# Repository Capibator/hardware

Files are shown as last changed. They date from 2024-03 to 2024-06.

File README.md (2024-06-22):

# V1.0 -> First tentative version with following features: 
made with Kicad, 2 layers, lots of vias :D 
- battery monitoring
- battery charge/discharge maintanance LIPO 
- buck boost regulator TPS 
- Source selector that can select between mcu_bat or +12V automatically
- An RTC that can keep time even without battery. helpful for critical memory and notifications. 
- An optional IO expander (PCF) providing 8 extra GPIO. can be left unpopulated. pcb should work fine. 
- MCU used is ESP32 with bluetooth and wifi hopefully both being utillized
- Heater and egg turner both AC, egg turner is the continous type and is the only type currently supported. 
- Main Voltage being used is +12V provided by jack, that will power fans, logic board. incase of power outage heavy stuff will be turned off automatically and it will go into power saving mode. 
- Outputs (All 12V)
    - Fan Exhaust 
    - Fan Continous 
    - Mist Maker 
    - LED lights 
    - Buzzer
    - Water Pump 
- Sensors/Inputs
    - Water level sensor
    - Display (I2C)
    - Rotary encoder for menu (left, right and click)
    - Temperature sensor (1 wire or digital)
    - Temperature sensor #2 (1 wire or digital)
- Indicators
    - Fault led, will light up if something is wrong according to code
    - Busy led, will turn on when turning eggs or saving to memory 
    - Con led, shows connectivity of wifi, if connected will light up
    - IO led, custom function or initial testing. 
    - Main power indicator led that will light up when 12V is connected through barrel jack. 

This is how it looks as of right now. 
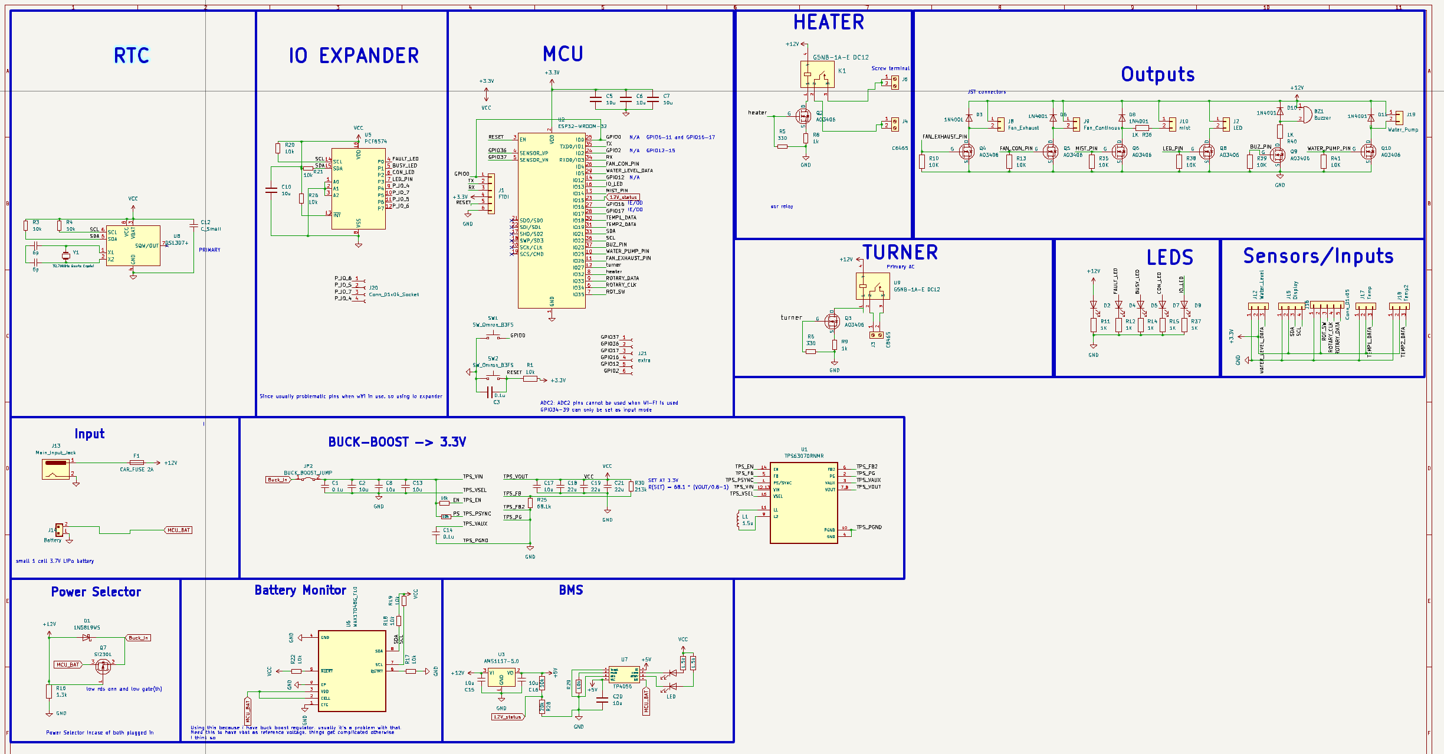
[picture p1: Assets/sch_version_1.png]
Version 1 schematic

PCB 
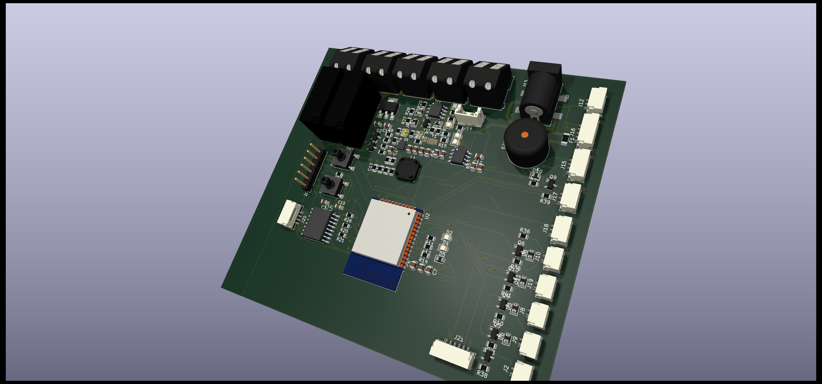
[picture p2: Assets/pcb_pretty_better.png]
Version 1 pcb


# Version 2 
Better placement, hopefully this is better. 
AC in one end and sensitive logic on the other. 
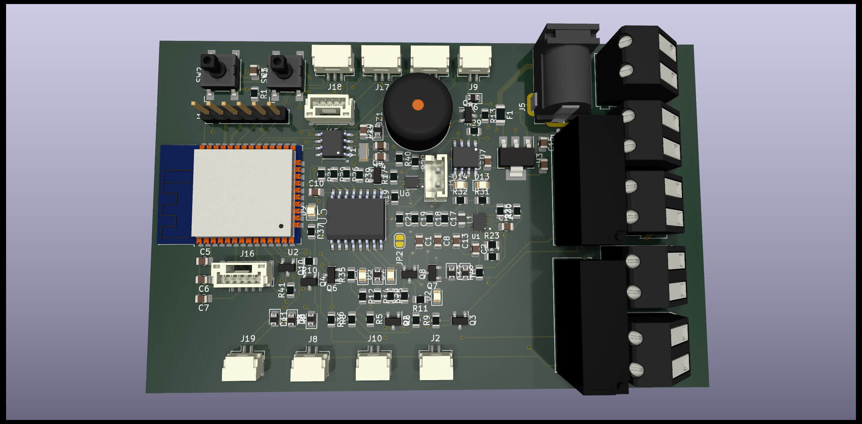
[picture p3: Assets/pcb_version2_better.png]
Version 2 pcb


size 101.5mm x 61.4mm

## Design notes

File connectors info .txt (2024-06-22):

connector consideration
group 1 small signal only and mA
temp1 3
temp2 3
water level 3

group 2 power 200
water pump 2
led 2
mist 2
fan continous 2
fan exhaust 2

group 3 signal only.
pcf extra 4 signal 
gpio 6 extra signal 
3.3V and gnd 

group 4
jst xh maybe? just signal
display 4 
rotary encoder 5

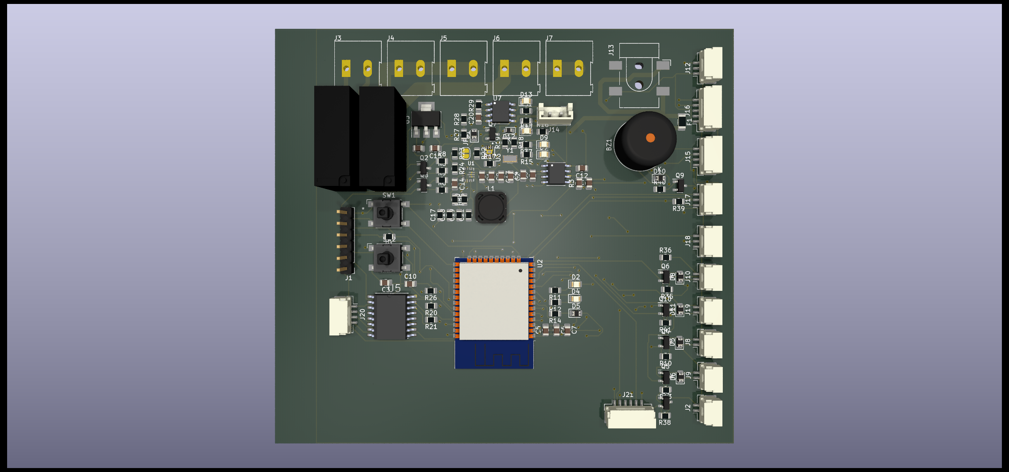
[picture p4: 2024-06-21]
Assets/pcb_pretty.png

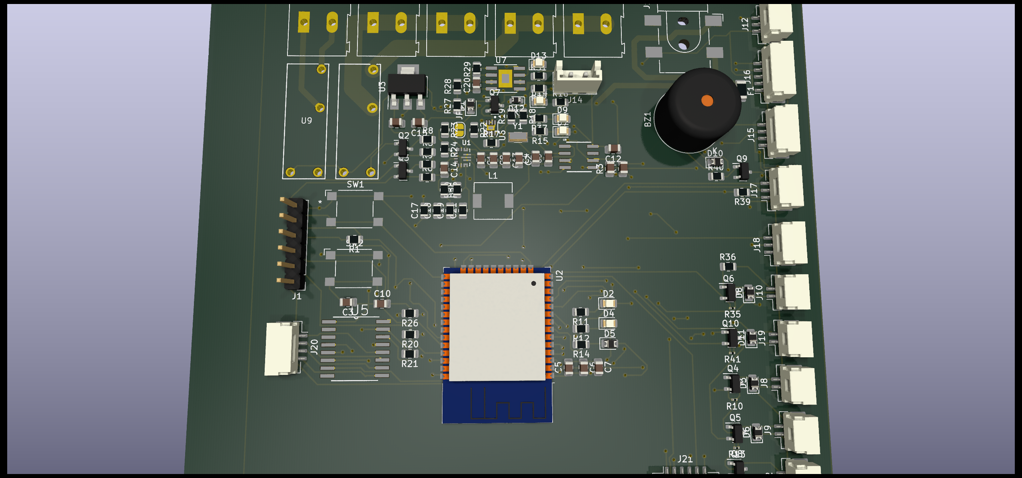
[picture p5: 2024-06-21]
Capibator_PCB_3DVIEW.png

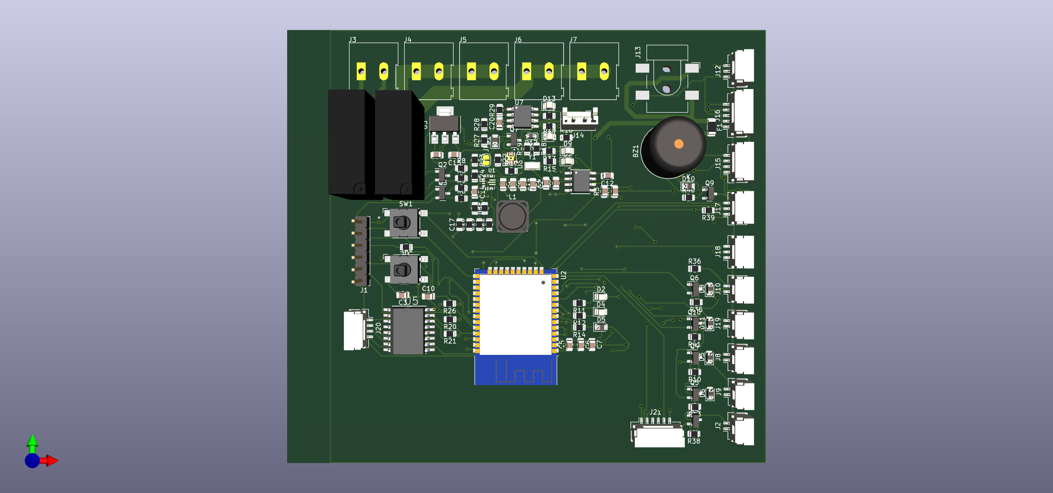
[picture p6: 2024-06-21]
Assets/pcb_simple.png

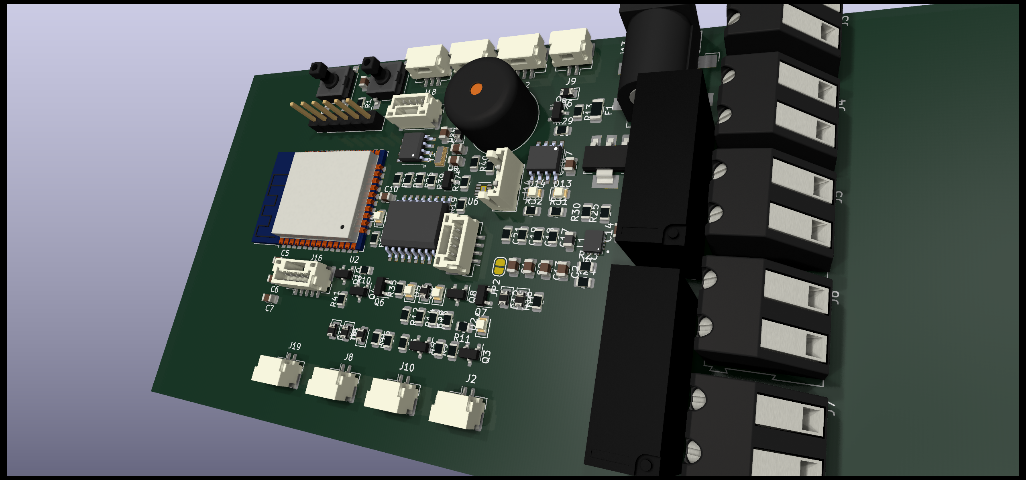
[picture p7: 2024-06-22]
Assets/version_2.png

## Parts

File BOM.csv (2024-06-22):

Reference | Value | Datasheet | Footprint | Qty | DNP
BZ1 | Buzzer | ~ | Buzzer_Beeper:Buzzer_12x9.5RM7.6 | 1
C1,C3,C14 | 0.1u | ~ | Capacitor_SMD:C_0805_2012Metric | 3
C2,C5,C6,C7,C8,C10,C13,C15,C16,C17,C20 | 10u | ~ | -- mixed values -- | 11
C4,C9 | 6p | ~ | Capacitor_SMD:C_0805_2012Metric | 2
C12 | C_Small | ~ | Capacitor_SMD:C_0805_2012Metric | 1
C18,C19,C21 | 22u | ~ | Resistor_SMD:R_0805_2012Metric | 3
D1 | 1N5819WS | https://datasheet.lcsc.com/lcsc/2204281430_Guangdong-Hottech-1N5819WS_C191023.pdf | Diode_SMD:D_0805_2012Metric | 1
D2 | LED_PWR | ~ | LED_SMD:LED_0805_2012Metric | 1
D3,D6,D8,D10,D11 | 1N4001 | http://www.vishay.com/docs/88503/1n4001.pdf | Diode_SMD:D_0805_2012Metric | 5
D4 | FAULT_LED | ~ | LED_SMD:LED_0805_2012Metric | 1
D5 | BUSY_LED | ~ | Diode_SMD:D_0805_2012Metric | 1
D7 | CONNECTIVITY_LED | ~ | LED_SMD:LED_0805_2012Metric | 1
D9,D13,D14,J2 | LED | ~ | -- mixed values -- | 4
F1 | CAR_FUSE 2A | ~ | Fuse:Fuse_1206_3216Metric | 1
J1 | FTDI | ~ | Connector_PinHeader_2.54mm:PinHeader_1x06_P2.54mm_Vertical | 1
J3,J4,J6 | C8465 | ~ | TerminalBlock:TerminalBlock_Altech_AK300-2_P5.00mm | 3
J5 | PJ-002AH |  | PJ-002AH:CUI_PJ-002AH | 1
J8 | Fan_Exhaust | ~ | Connector_JST:JST_GH_SM02B-GHS-TB_1x02-1MP_P1.25mm_Horizontal | 1
J9 | Fan_Continous | ~ | Connector_JST:JST_GH_SM02B-GHS-TB_1x02-1MP_P1.25mm_Horizontal | 1
J10 | mist | ~ | Connector_JST:JST_GH_SM02B-GHS-TB_1x02-1MP_P1.25mm_Horizontal | 1
J12 | Water_Level | ~ | Connector_JST:JST_GH_SM03B-GHS-TB_1x03-1MP_P1.25mm_Horizontal | 1
J14 | Battery |  | Connector_JST:JST_EH_B2B-EH-A_1x02_P2.50mm_Vertical | 1
J15 | Display | ~ | Connector_JST:JST_GH_BM04B-GHS-TBT_1x04-1MP_P1.25mm_Vertical | 1
J16 | Rotary encoder | ~ | Connector_JST:JST_GH_BM05B-GHS-TBT_1x05-1MP_P1.25mm_Vertical | 1
J17 | Temp | ~ | Connector_JST:JST_GH_SM03B-GHS-TB_1x03-1MP_P1.25mm_Horizontal | 1
J18 | Temp2 | ~ | Connector_JST:JST_GH_SM03B-GHS-TB_1x03-1MP_P1.25mm_Horizontal | 1
J19 | Water_Pump | ~ | Connector_JST:JST_GH_SM02B-GHS-TB_1x02-1MP_P1.25mm_Horizontal | 1
JP2 | BUCK_BOOST_JUMP | ~ | Jumper:SolderJumper-2_P1.3mm_Bridged_RoundedPad1.0x1.5mm | 1
K1,U9 | G5NB-1A-E DC12 | -- mixed values -- | G5NB-1A-E_DC12:RELAY_G5NB-1A_DC5_OMR | 2
L1 | 1.5u | ~ | Inductor_SMD:L_0805_2012Metric | 1
Q2,Q3,Q4,Q5,Q6,Q8,Q9,Q10 | AO3406 | https://ngspice.sourceforge.io/docs/ngspice-manual.pdf | Package_TO_SOT_SMD:SOT-23 | 8
Q7 | SI2301 | http://www.vishay.com/docs/66709/si2319cd.pdf | Package_TO_SOT_SMD:SOT-23 | 1
R1,R17,R20,R21,R22,R23,R24,R26,R29 | 10k | ~ | Resistor_SMD:R_0805_2012Metric | 9
R5,R6 | 330 | ~ | Resistor_SMD:R_0805_2012Metric | 2
R8,R9 | 1k | ~ | Resistor_SMD:R_0805_2012Metric | 2
R10,R13,R35,R38,R39,R41 | 10K | ~ | Resistor_SMD:R_0805_2012Metric | 6
R11,R12,R14,R15,R36,R37,R40 | 1K | ~ | Resistor_SMD:R_0805_2012Metric | 7
R16 | 1.3k | ~ | Resistor_SMD:R_0805_2012Metric | 1
R25 | 68.1k | ~ | Resistor_SMD:R_0805_2012Metric | 1
R30 | 213k | ~ | Resistor_SMD:R_0805_2012Metric | 1
R31,R32 | 1.5k | ~ | Resistor_SMD:R_0805_2012Metric | 2
SW1,SW2 | SW_Omron_B3FS | https://omronfs.omron.com/en_US/ecb/products/pdf/en-b3fs.pdf | Button_Switch_SMD:SW_SPST_Omron_B3FS-100xP | 2
U1 | TPS63070RNMR |  | TPS63070RNMR:VREG_TPS63070RNMR | 1
U2 | ESP32-WROOM-32 | https://www.espressif.com/sites/default/files/documentation/esp32-wroom-32_datasheet_en.pdf | RF_Module:ESP32-WROOM-32 | 1
U3 | AMS1117-5.0 | http://www.advanced-monolithic.com/pdf/ds1117.pdf | Package_TO_SOT_SMD:SOT-223-3_TabPin2 | 1
U5 | PCF8574 | http://www.nxp.com/docs/en/data-sheet/PCF8574_PCF8574A.pdf | PCF8574T_3_518:SOIC127P1032X265-16N | 1
U6 | MAX17048G_T10 |  | MAX17048G_T10:SON50P200X200X80-9N | 1
U7 | TP4056 |  | TP4056:SOP127P600X175-9N | 1
U8 | DS1307+ | https://datasheets.maximintegrated.com/en/ds/DS1307.pdf | DS1307ZTR:21-0041B_8 | 1
Y1 | 32.768kHz Quartz Crystal | ~ | Crystal:Crystal_SMD_3215-2Pin_3.2x1.5mm | 1

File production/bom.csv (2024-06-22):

Designator | Footprint | Quantity | Value | LCSC Part #
BZ1 | Buzzer_12x9.5RM7.6 | 1 | Buzzer
C1, C14, C3 | 0805 | 3 | 0.1u
C10, C12, C13, C15, C16, C17, C2, C20, C5, C6, C7, C8 | 0805 | 12 | 10u
C18, C19, C21 | 0805 | 3 | 22u
C4, C9 | 0805 | 2 | 6p
D1 | D_SOD-323F | 1 | 1N5819WS
D10, D11, D3, D6, D8 | D_SOD-123F | 5 | 1N4001
D13, D14, D9 | 0805 | 3 | LED
D2 | 0805 | 1 | LED_PWR
D4 | 0805 | 1 | FAULT_LED
D5 | 0805 | 1 | BUSY_LED
D7 | 0805 | 1 | CONNECTIVITY_LED
J1 | PinHeader_1x06_P2.54mm_Vertical | 1 | FTDI
J10 | JST_GH_SM02B-GHS-TB_1x02-1MP_P1.25mm_Horizontal | 1 | mist
J12 | JST_GH_SM03B-GHS-TB_1x03-1MP_P1.25mm_Horizontal | 1 | Water_Level
J14 | JST_EH_B2B-EH-A_1x02_P2.50mm_Vertical | 1 | Battery
J15 | JST_GH_BM04B-GHS-TBT_1x04-1MP_P1.25mm_Vertical | 1 | Display
J16 | JST_GH_BM05B-GHS-TBT_1x05-1MP_P1.25mm_Vertical | 1 | Rotary encoder
J17 | JST_GH_SM03B-GHS-TB_1x03-1MP_P1.25mm_Horizontal | 1 | Temp
J18 | JST_GH_SM03B-GHS-TB_1x03-1MP_P1.25mm_Horizontal | 1 | Temp2
J19 | JST_GH_SM02B-GHS-TB_1x02-1MP_P1.25mm_Horizontal | 1 | Water_Pump
J2 | JST_GH_SM02B-GHS-TB_1x02-1MP_P1.25mm_Horizontal | 1 | LED
J3, J4, J6 | TerminalBlock_Altech_AK300-2_P5.00mm | 3 | C8465
J5_2 | CUI_PJ-002AH | 1 | PJ-002AH
J5, J7 | TerminalBlock_Altech_AK300-2_P5.00mm | 2 | Screw_Terminal_01x02
J8 | JST_GH_SM02B-GHS-TB_1x02-1MP_P1.25mm_Horizontal | 1 | Fan_Exhaust
J9 | JST_GH_SM02B-GHS-TB_1x02-1MP_P1.25mm_Horizontal | 1 | Fan_Continous
JP2 | SolderJumper-2_P1.3mm_Bridged_RoundedPad1.0x1.5mm | 1 | BUCK_BOOST_JUMP
K1, U9 | RELAY_G5NB-1A_DC5_OMR | 2 | G5NB-1A-E DC12
L1 | L_Murata_LQH2MCNxxxx02_2.0x1.6mm | 1 | 1.5u
Q10, Q2, Q3, Q4, Q5, Q6, Q8, Q9 | SOT-23 | 8 | AO3406
Q7 | SOT-23 | 1 | SI2301
R1, R10, R13, R17, R19, R20, R21, R22, R23, R24, R26, R29, R35, R38, R39, R41 | 0805 | 16 | 10k
R11, R12, R14, R15, R31, R32, R37 | 0805 | 7 | 100
R16 | 0805 | 1 | 1.3k
R2 | 0805 | 1 | 3k
R25 | 0805 | 1 | 68.1k
R30 | 0805 | 1 | 210k
R36 | D_SOD-123F | 1 | 1K
R40, R8, R9 | 0805 | 3 | 1K
R5, R6 | 0805 | 2 | 330
SW1, SW2 | SW_SPST_Omron_B3FS-100xP | 2 | SW_Omron_B3FS
U1 | VREG_TPS63070RNMR | 1 | TPS63070RNMR
U2 | ESP32-WROOM-32 | 1 | ESP32-WROOM-32
U3 | SOT-223-3_TabPin2 | 1 | AMS1117-5.0
U5 | SOIC127P1032X265-16N | 1 | PCF8574
U6 | SON50P200X200X80-9N | 1 | MAX17048G_T10
U7 | SOP127P600X175-9N | 1 | TP4056
U8 | 21-0041B_8 | 1 | DS1307+
Y1 | Crystal_SMD_2012-2Pin_2.0x1.2mm_HandSoldering | 1 | 32.768kHz Quartz Crystal

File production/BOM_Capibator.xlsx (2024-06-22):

Designator | Footprint | Quantity | Value | LCSC Part #
BZ1 | Buzzer_12x9.5RM7.6 | 1 | Buzzer | C7496513 (https://www.lcsc.com/product-detail/Buzzers_KINGSTATE-KXG1212C_C7496513.html)
C1, C14, C3 | 805 | 3 | 0.1u | C49678 (https://www.lcsc.com/product-detail/Multilayer-Ceramic-Capacitors-MLCC-SMD-SMT_YAGEO-CC0805KRX7R9BB104_C49678.html)
C10, C12, C13, C15, C16, C17, C2, C20, C5, C6, C7, C8 | 805 | 12 | 10u | C40894 (https://www.lcsc.com/product-detail/Multilayer-Ceramic-Capacitors-MLCC-SMD-SMT_FH-Guangdong-Fenghua-Advanced-Tech-0805X106K250NT_C40894.html)
C18, C19, C21 | 805 | 3 | 22u | C129303 (https://www.lcsc.com/product-detail/Multilayer-Ceramic-Capacitors-MLCC-SMD-SMT_FH-Guangdong-Fenghua-Advanced-Tech-0805X226M250NT_C129303.html)
C4, C9 | 805 | 2 | 6p | C67560 (https://www.lcsc.com/product-detail/Multilayer-Ceramic-Capacitors-MLCC-SMD-SMT_FH-Guangdong-Fenghua-Advanced-Tech-0805CG6R0C500NT_C67560.html)
D1 | D_SOD-323F | 1 | 1N5819WS | C727116 (https://www.lcsc.com/product-detail/Schottky-Barrier-Diodes-SBD_TWGMC-1N5819WS_C727116.html)
D10, D11, D3, D6, D8 | D_SOD-123F | 5 | 1N4001 | C2892326 (https://www.lcsc.com/product-detail/Diodes-General-Purpose_YONGYUTAI-1N4001_C2892326.html)
D13, D9, D5, D2, D14, D4, D7 | 805 | 3 | LED | C5349940 (https://www.lcsc.com/product-detail/Light-Emitting-Diodes-LED_XINGLIGHT-XL-TD2012UBC_C5349940.html)
J1 | PinHeader_1x06_P2.54mm_Vertical | 1 | FTDI | C19190481 (https://www.lcsc.com/product-detail/Pin-Headers_Yxcon-P125-1106A0BS116A1_C19190481.html)
J10 | JST_GH_SM02B-GHS-TB_1x02-1MP_P1.25mm_Horizontal | 1 | mist | C160402 (https://www.lcsc.com/product-detail/Wire-To-Board-Connector_JST-SM02B-SRSS-TB-LF-SN_C160402.html)
J12 | JST_GH_SM03B-GHS-TB_1x03-1MP_P1.25mm_Horizontal | 1 | Water_Level | C514175 (https://www.lcsc.com/product-detail/Wire-To-Board-Connector_JST-SM03B-GHS-TB-LF-SN_C514175.html)
J14 | JST_EH_B2B-EH-A_1x02_P2.50mm_Vertical | 1 | Battery | C160262 (https://www.lcsc.com/product-detail/Wire-To-Board-Connector_JST-B2B-EH-A-LF-SN_C160262.html)
J15 | JST_GH_BM04B-GHS-TBT_1x04-1MP_P1.25mm_Vertical | 1 | Display | C161692 (https://www.lcsc.com/product-detail/Wire-To-Board-Connector_JST-BM04B-GHS-TBT-LF-SN_C161692.html)
J16 | JST_GH_BM05B-GHS-TBT_1x05-1MP_P1.25mm_Vertical | 1 | Rotary encoder | C189891 (https://www.lcsc.com/product-detail/Wire-To-Board-Connector_JST-BM05B-GHS-TBT-LF-SN-N_C189891.html)
J17 | JST_GH_SM03B-GHS-TB_1x03-1MP_P1.25mm_Horizontal | 1 | Temp | C514175 (https://www.lcsc.com/product-detail/Wire-To-Board-Connector_JST-SM03B-GHS-TB-LF-SN_C514175.html)
J18 | JST_GH_SM03B-GHS-TB_1x03-1MP_P1.25mm_Horizontal | 1 | Temp2 | C514175 (https://www.lcsc.com/product-detail/Wire-To-Board-Connector_JST-SM03B-GHS-TB-LF-SN_C514175.html)
J19 | JST_GH_SM02B-GHS-TB_1x02-1MP_P1.25mm_Horizontal | 1 | Water_Pump | C189893 (https://www.lcsc.com/product-detail/Wire-To-Board-Connector_JST-SM02B-GHS-TB-LF-SN_C189893.html)
J2 | JST_GH_SM02B-GHS-TB_1x02-1MP_P1.25mm_Horizontal | 1 | LED | C189893 (https://www.lcsc.com/product-detail/Wire-To-Board-Connector_JST-SM02B-GHS-TB-LF-SN_C189893.html)
J3, J4, J6, J5, J7 | TerminalBlock_Altech_AK300-2_P5.00mm | 3 | terminal_con | C8465 (https://www.lcsc.com/product-detail/Screw-terminal_Ningbo-Kangnex-Elec-WJ500V-5-08-2P_C8465.html)
J20 | CUI_PJ-002AH | 1 | PJ-002AH | C319099 (https://www.lcsc.com/product-detail/span-style-background-color-ff0-DC-span-Power-Connector_XKB-Connection-DC-005-2-5A-2-0_C319099.html)
J8 | JST_GH_SM02B-GHS-TB_1x02-1MP_P1.25mm_Horizontal | 1 | Fan_Exhaust | C189893 (https://www.lcsc.com/product-detail/Wire-To-Board-Connector_JST-SM02B-GHS-TB-LF-SN_C189893.html)
J9 | JST_GH_SM02B-GHS-TB_1x02-1MP_P1.25mm_Horizontal | 1 | Fan_Continous | C189893 (https://www.lcsc.com/product-detail/Wire-To-Board-Connector_JST-SM02B-GHS-TB-LF-SN_C189893.html)
K1, U9 | RELAY_G5NB-1A_DC5_OMR | 2 | G5NB-1A-E DC12 | C225714 (https://www.lcsc.com/product-detail/Power-Relays_Omron-Electronics-G5NB-1A-E-DC12_C225714.html)
L1 | L_Murata_LQH2MCNxxxx02_2.0x1.6mm | 1 | 1.5u | C326262 (https://www.lcsc.com/product-detail/Inductors-SMD_3-span-style-background-color-ff0-L-span-COILS-SNR2010K-1R5M_C326262.html)
Q10, Q2, Q3, Q4, Q5, Q6, Q8, Q9 | SOT-23 | 8 | AO3406 | C2909910 (https://www.lcsc.com/product-detail/MOSFETs_KUU-AO3406_C2909910.html)
Q7 | SOT-23 | 1 | SI2301 | C5261052 (https://www.lcsc.com/product-detail/MOSFETs_HXY-MOSFET-SI2301-ZE_C5261052.html)
R1, R10, R13, R17, R19, R20, R21, R22, R23, R24, R26, R29, R35, R38, R39, R41 | 805 | 16 | 10k | C17414 (https://www.lcsc.com/product-detail/Chip-Resistor-Surface-Mount_UNI-ROYAL-Uniroyal-Elec-0805W8F1002T5E_C17414.html)
R11, R12, R14, R15, R31, R32, R37 | 805 | 9 | 100 | C17408 (https://www.lcsc.com/product-detail/Chip-Resistor-Surface-Mount_UNI-ROYAL-Uniroyal-Elec-0805W8F1000T5E_C17408.html)
R16 | 805 | 1 | 1.3k | C2933303 (https://www.lcsc.com/product-detail/Chip-Resistor-Surface-Mount_FOJAN-FRC0805F1301TS_C2933303.html)
R2 | 805 | 1 | 3k | C109322 (https://www.lcsc.com/product-detail/DC-DC-Converters_Texas-Instruments-TPS63070RNMR_C109322.html)
R25 | 805 | 1 | 68.1k | C17795 (https://www.lcsc.com/product-detail/Chip-Resistor-Surface-Mount_UNI-ROYAL-Uniroyal-Elec-0805W8F6812T5E_C17795.html)
R30 | 805 | 1 | 210k | C17547 (https://www.lcsc.com/product-detail/Chip-Resistor-Surface-Mount_UNI-ROYAL-Uniroyal-Elec-0805W8F2103T5E_C17547.html)
R36, R40, R8, R9 | 805 | 4 | 1K | C17513 (https://www.lcsc.com/product-detail/Chip-Resistor-Surface-Mount_UNI-ROYAL-Uniroyal-Elec-0805W8F1001T5E_C17513.html)
SW1, SW2 | SW_SPST_Omron_B3FS-100xP | 2 | SW_Omron_B3FS | C87038 (https://www.lcsc.com/product-detail/Tactile-Switches_Omron-Electronics-B3FS-1002P_C87038.html)
U1 | VREG_TPS63070RNMR | 1 | TPS63070RNMR | C109322 (https://www.lcsc.com/product-detail/DC-DC-Converters_Texas-Instruments-TPS63070RNMR_C109322.html)
U2 | ESP32-WROOM-32 | 1 | ESP32-WROOM-32 | C701342 (https://www.lcsc.com/product-detail/WiFi-Modules_Espressif-Systems-ESP32-WROOM-32E-N8_C701342.html)
U3 | SOT-223-3_TabPin2 | 1 | AMS1117-5.0 | C18212701 (https://www.lcsc.com/product-detail/Linear-Voltage-Regulators-LDO_TECH-PUBLIC-AMS1117-5-0_C18212701.html)
U5 | SOIC127P1032X265-16N | 1 | PCF8574 | C2987288 (https://www.lcsc.com/product-detail/I-O-Expanders_HGSEMI-PCF8574T-TR_C2987288.html)
U6 | SON50P200X200X80-9N | 1 | MAX17048G_T10 | C2682616 (https://www.lcsc.com/product-detail/Battery-Management-ICs_Analog-Devices-Inc-Maxim-Integrated-MAX17048G-T10_C2682616.html)
U7 | SOP127P600X175-9N | 1 | TP4056 | C16581 (https://www.lcsc.com/product-detail/Battery-Management-ICs_TOPPOWER-Nanjing-Extension-Microelectronics-TP4056-42-ESOP8_C16581.html)
U8 | 21-0041B_8 | 1 | DS1307+ | C5145427 (https://www.lcsc.com/product-detail/Real-Time-Clocks-RTC_HANSCHIP-semiconductor-DS1307CDRG_C5145427.html)
Y1 | Crystal_SMD_2012-2Pin_2.0x1.2mm_HandSoldering | 1 | 32.768kHz Quartz Crystal | C620155 (https://www.lcsc.com/product-detail/Crystals_YXC-Crystal-Oscillators-X321532768KGD2SI_C620155.html)

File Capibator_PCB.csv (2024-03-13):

# | Reference | Qty | Value | Footprint | DNP
1 | BZ1 | 1 | Buzzer | Buzzer_Beeper:Buzzer_12x9.5RM7.6
2 | C1, C3, C14 | 3 | 0.1u | Capacitor_SMD:C_0402_1005Metric
3 | C2, C5, C6, C7, C8, C13, C15, C17, C20 | 9 | 10u | Capacitor_SMD:C_0402_1005Metric
4 | C4, C9 | 2 | 6p | Capacitor_SMD:C_0402_1005Metric
5 | C12 | 1 | C_Small | Capacitor_SMD:C_0402_1005Metric
6 | C16 | 1 | 10u | Capacitor_SMD:C_0805_2012Metric
7 | C18, C19, C21 | 3 | 22u | Capacitor_SMD:C_0402_1005Metric
8 | D2 | 1 | LED_PWR | LED_SMD:LED_0805_2012Metric
9 | D3, D6, D8, D10, D11 | 5 | 1N4001 | Diode_SMD:D_0805_2012Metric
10 | D4 | 1 | FAULT_LED | LED_SMD:LED_0805_2012Metric
11 | D5 | 1 | BUSY_LED | Diode_SMD:D_0805_2012Metric
12 | D7 | 1 | CONNECTIVITY_LED | LED_SMD:LED_0805_2012Metric
13 | D9, D13, D14 | 3 | LED | LED_SMD:LED_0805_2012Metric
14 | D12 | 1 | 1N5819 | Diode_SMD:D_0805_2012Metric
15 | F1 | 1 | CAR_FUSE 2A | Fuse:Fuse_1206_3216Metric
16 | J1 | 1 | FTDI | Connector_PinHeader_2.54mm:PinHeader_1x06_P2.54mm_Horizontal
17 | J3, J4, J6 | 3 | C8465 | TerminalBlock:TerminalBlock_Altech_AK300-2_P5.00mm
18 | J5, J7 | 2 | Screw_Terminal_01x02 | TerminalBlock:TerminalBlock_Altech_AK300-2_P5.00mm
19 | J8 | 1 | Fan_Exhaust | Connector_JST:JST_GH_SM02B-GHS-TB_1x02-1MP_P1.25mm_Horizontal
20 | J9 | 1 | Fan_Continous | Connector_JST:JST_GH_SM02B-GHS-TB_1x02-1MP_P1.25mm_Horizontal
21 | J10 | 1 | mist | Connector_JST:JST_GH_SM02B-GHS-TB_1x02-1MP_P1.25mm_Horizontal
22 | J11 | 1 | Led | LED_SMD:LED_0805_2012Metric
23 | J12 | 1 | Water_Level | Connector_JST:JST_GH_SM03B-GHS-TB_1x03-1MP_P1.25mm_Horizontal
24 | J13 | 1 | Main_Input_Jack | Connector_BarrelJack:BarrelJack_CLIFF_FC681465S_SMT_Horizontal
25 | J14 | 1 | Battery | Connector_JST:JST_EH_B2B-EH-A_1x02_P2.50mm_Vertical
26 | J15 | 1 | Display | Connector_JST:JST_GH_SM04B-GHS-TB_1x04-1MP_P1.25mm_Horizontal
27 | J16 | 1 | Rotary_Encoder | Connector_JST:JST_GH_SM03B-GHS-TB_1x03-1MP_P1.25mm_Horizontal
28 | J17 | 1 | Temp | Connector_JST:JST_GH_SM03B-GHS-TB_1x03-1MP_P1.25mm_Horizontal
29 | J18 | 1 | Temp2 | Connector_JST:JST_GH_SM03B-GHS-TB_1x03-1MP_P1.25mm_Horizontal
30 | J19 | 1 | Water_Pump | Connector_JST:JST_GH_SM02B-GHS-TB_1x02-1MP_P1.25mm_Horizontal
31 | J20 | 1 | Conn_01x04_Socket | Connector_JST:JST_GH_SM04B-GHS-TB_1x04-1MP_P1.25mm_Horizontal
32 | J21 | 1 | extra | Connector_JST:JST_GH_SM06B-GHS-TB_1x06-1MP_P1.25mm_Horizontal
33 | JP1 | 1 | Jumper_3_Bridged12 | Jumper:SolderJumper-3_P1.3mm_Bridged2Bar12_Pad1.0x1.5mm_NumberLabels
34 | JP2 | 1 | BUCK_BOOST_JUMP | Jumper:SolderJumper-2_P1.3mm_Bridged_RoundedPad1.0x1.5mm
35 | JP3 | 1 | Jumper_2_Open | Jumper:SolderJumper-2_P1.3mm_Open_Pad1.0x1.5mm
36 | L1 | 1 | 1.5u | Inductor_SMD:L_6.3x6.3_H3
37 | Q2, Q3, Q4, Q5, Q6, Q8, Q9, Q10 | 8 | AO3406 | Package_TO_SOT_SMD:SOT-23
38 | Q7 | 1 | SI2301 | Package_TO_SOT_SMD:SOT-23
39 | R1, R3, R4, R17, R18, R19, R20, R21, R22, R23, R24, R26, R27, R29 | 14 | 10k | Resistor_SMD:R_0201_0603Metric
40 | R5, R6 | 2 | 330 | Resistor_SMD:R_0201_0603Metric
41 | R8, R9 | 2 | 1k | Resistor_SMD:R_0201_0603Metric
42 | R10, R13, R35, R38, R39, R41 | 6 | 10K | Resistor_SMD:R_0201_0603Metric
43 | R11, R12, R14, R15 | 4 | 1K | Resistor_SMD:R_0201_0603Metric
44 | R16 | 1 | 1.3k | Resistor_SMD:R_0201_0603Metric
45 | R25 | 1 | 68.1k | Resistor_SMD:R_0201_0603Metric
46 | R28 | 1 | 20k | Resistor_SMD:R_0201_0603Metric
47 | R30 | 1 | 213k | Resistor_SMD:R_0201_0603Metric
48 | R31, R32 | 2 | 1.5k | Resistor_SMD:R_0201_0603Metric
49 | R36, R37, R40 | 3 | 1K | Resistor_SMD:R_0805_2012Metric
50 | SW1, SW2 | 2 | SW_MEC_5G | Button_Switch_SMD:SW_SPST_B3U-1000P
51 | SW4 | 1 | SW | Button_Switch_SMD:Nidec_Copal_CAS-120A
52 | U1, U4 | 2 | ~ | Package_DFN_QFN:TDFN-8-1EP_2x2mm_P0.5mm_EP0.8x1.2mm
53 | U2 | 1 | ESP32-WROOM-32 | RF_Module:ESP32-WROOM-32
54 | U5 | 1 | PCF8574 | PCF8574T_3_518:SOIC127P1032X265-16N
55 | U6 | 1 | LM7805_TO220 | Package_TO_SOT_THT:TO-220F-3_Horizontal_TabDown
56 | U7 | 1 | TP4056 | TP4056:SOP127P600X175-9N
57 | U8 | 1 | DS1307+ | Package_DIP:DIP-8_W7.62mm
58 | U9, U10 | 2 | G5NB-1A-E DC12 | Package_SIP:SIP4_Sharp-SSR_P7.62mm_Straight
59 | Y1 | 1 | 32.768kHz Quartz Crystal | Crystal:Crystal_SMD_3215-2Pin_3.2x1.5mm

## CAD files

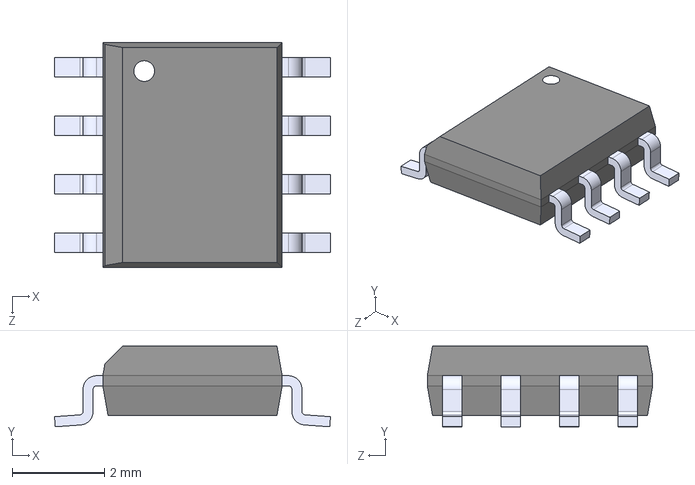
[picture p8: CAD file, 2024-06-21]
DS1307ZTR/DS1307ZTR.step
6.00 x 1.75 x 4.90 mm

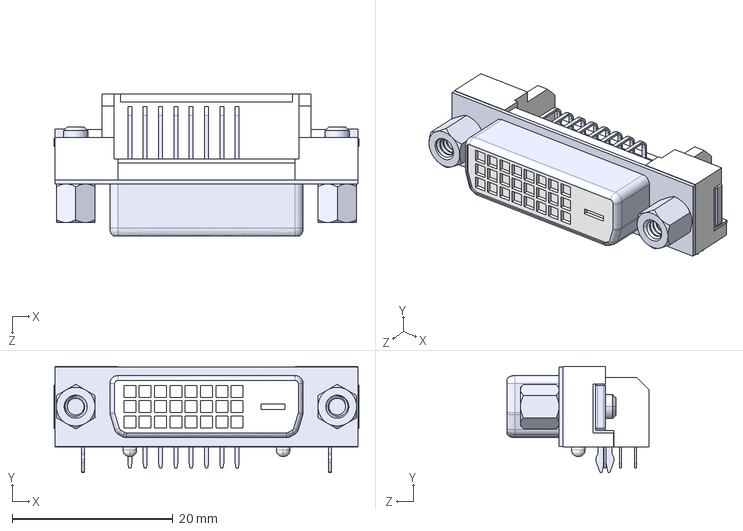
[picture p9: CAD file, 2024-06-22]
DVI-D connector/3JL-25S-4244.step
37.9 x 13.2 x 17.7 mm

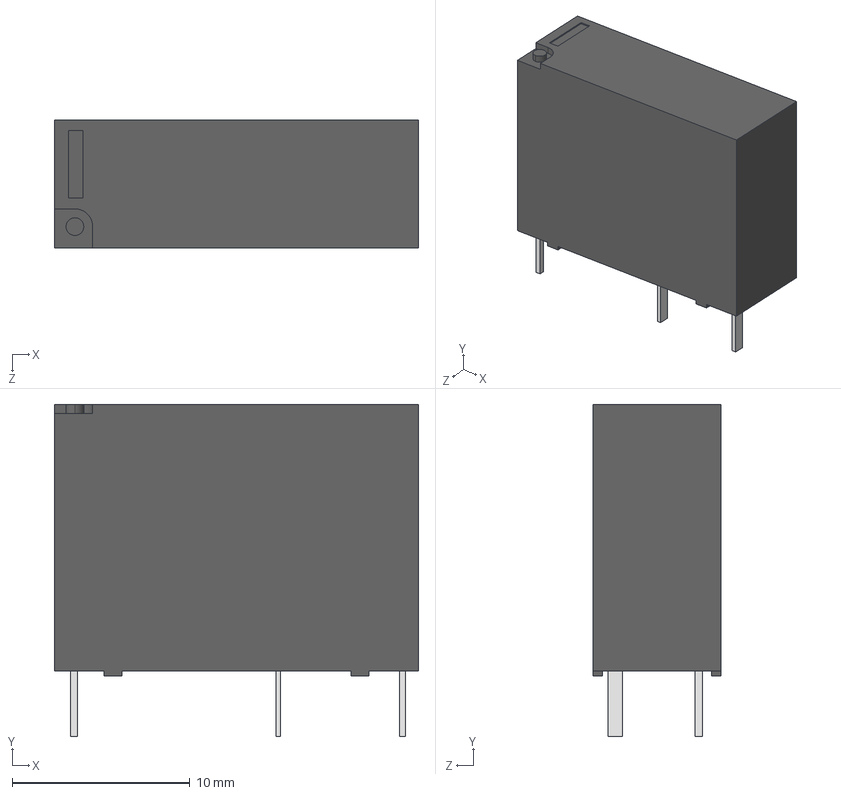
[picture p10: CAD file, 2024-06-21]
G5NB-1A-E DC12--3DModel-STEP-1.STEP
20.5 x 18.7 x 7.20 mm

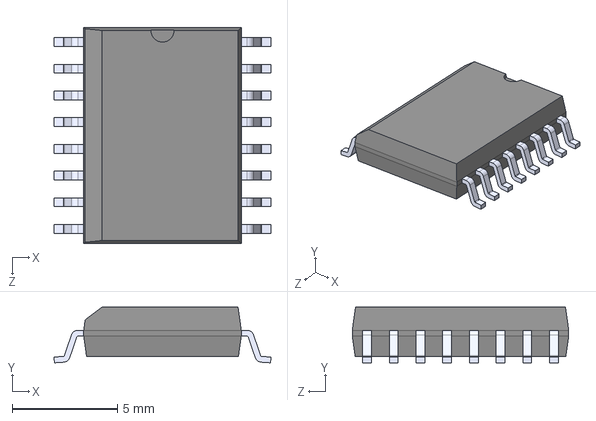
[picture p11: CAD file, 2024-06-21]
PCF8574T_3_518/PCF8574T_3_518.step
10.3 x 2.65 x 10.3 mm

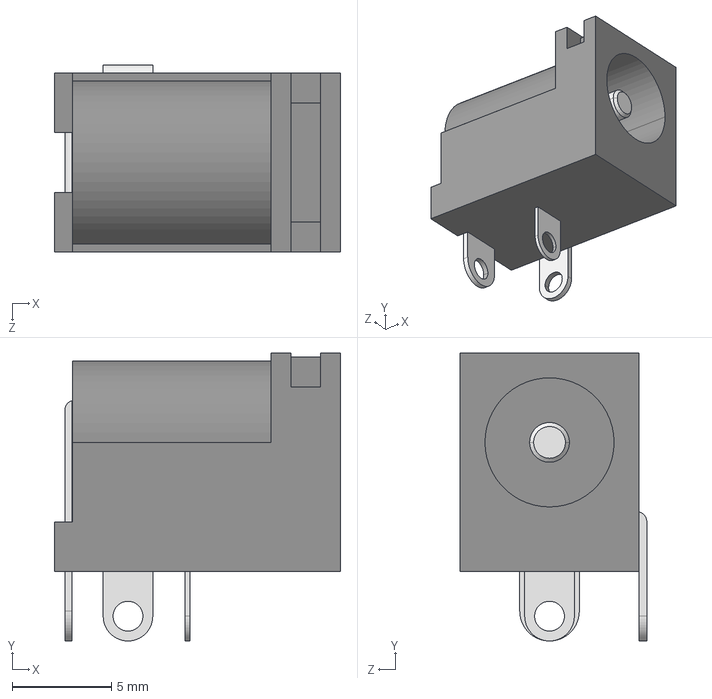
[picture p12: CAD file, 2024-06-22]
PJ-002AH/CUI_DEVICES_PJ-002AH.step
14.4 x 14.5 x 9.40 mm

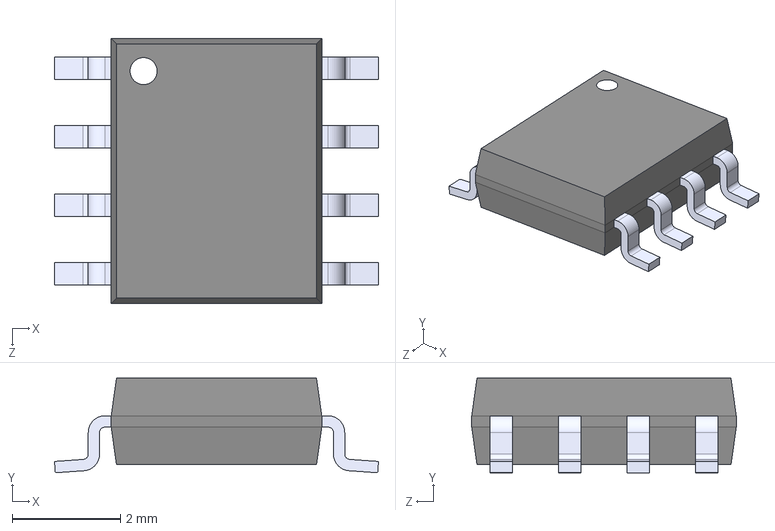
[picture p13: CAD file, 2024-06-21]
TP4056/TP4056.step
6.00 x 1.75 x 4.90 mm

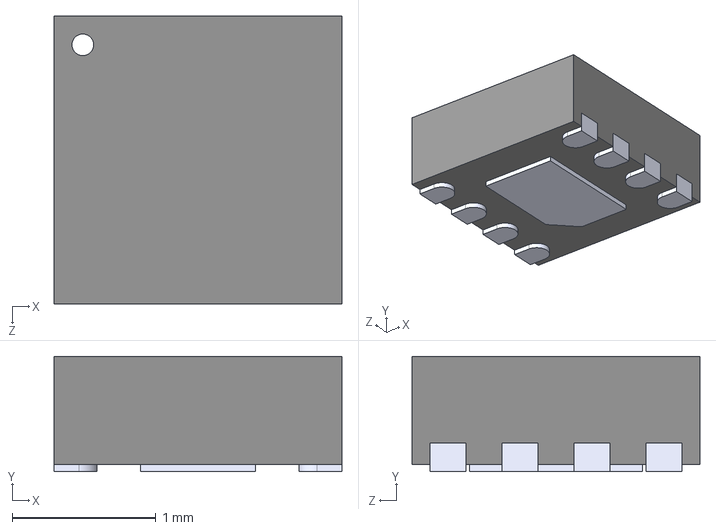
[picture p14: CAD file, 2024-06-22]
MAX17048G_T10/MAX17048G_T10.step
2.00 x 0.8 x 2.00 mm

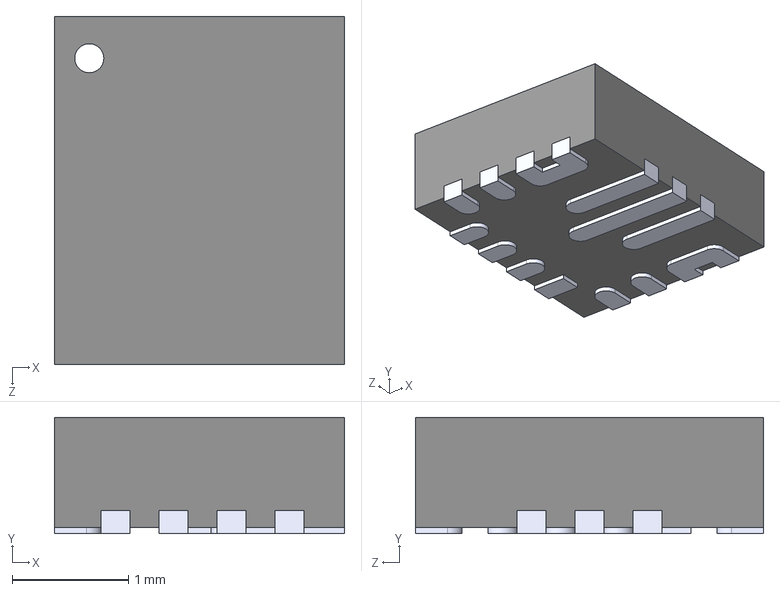
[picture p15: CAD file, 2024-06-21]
TPS63070RNMR/TPS63070RNMR.step
2.50 x 1.00 x 3.00 mm

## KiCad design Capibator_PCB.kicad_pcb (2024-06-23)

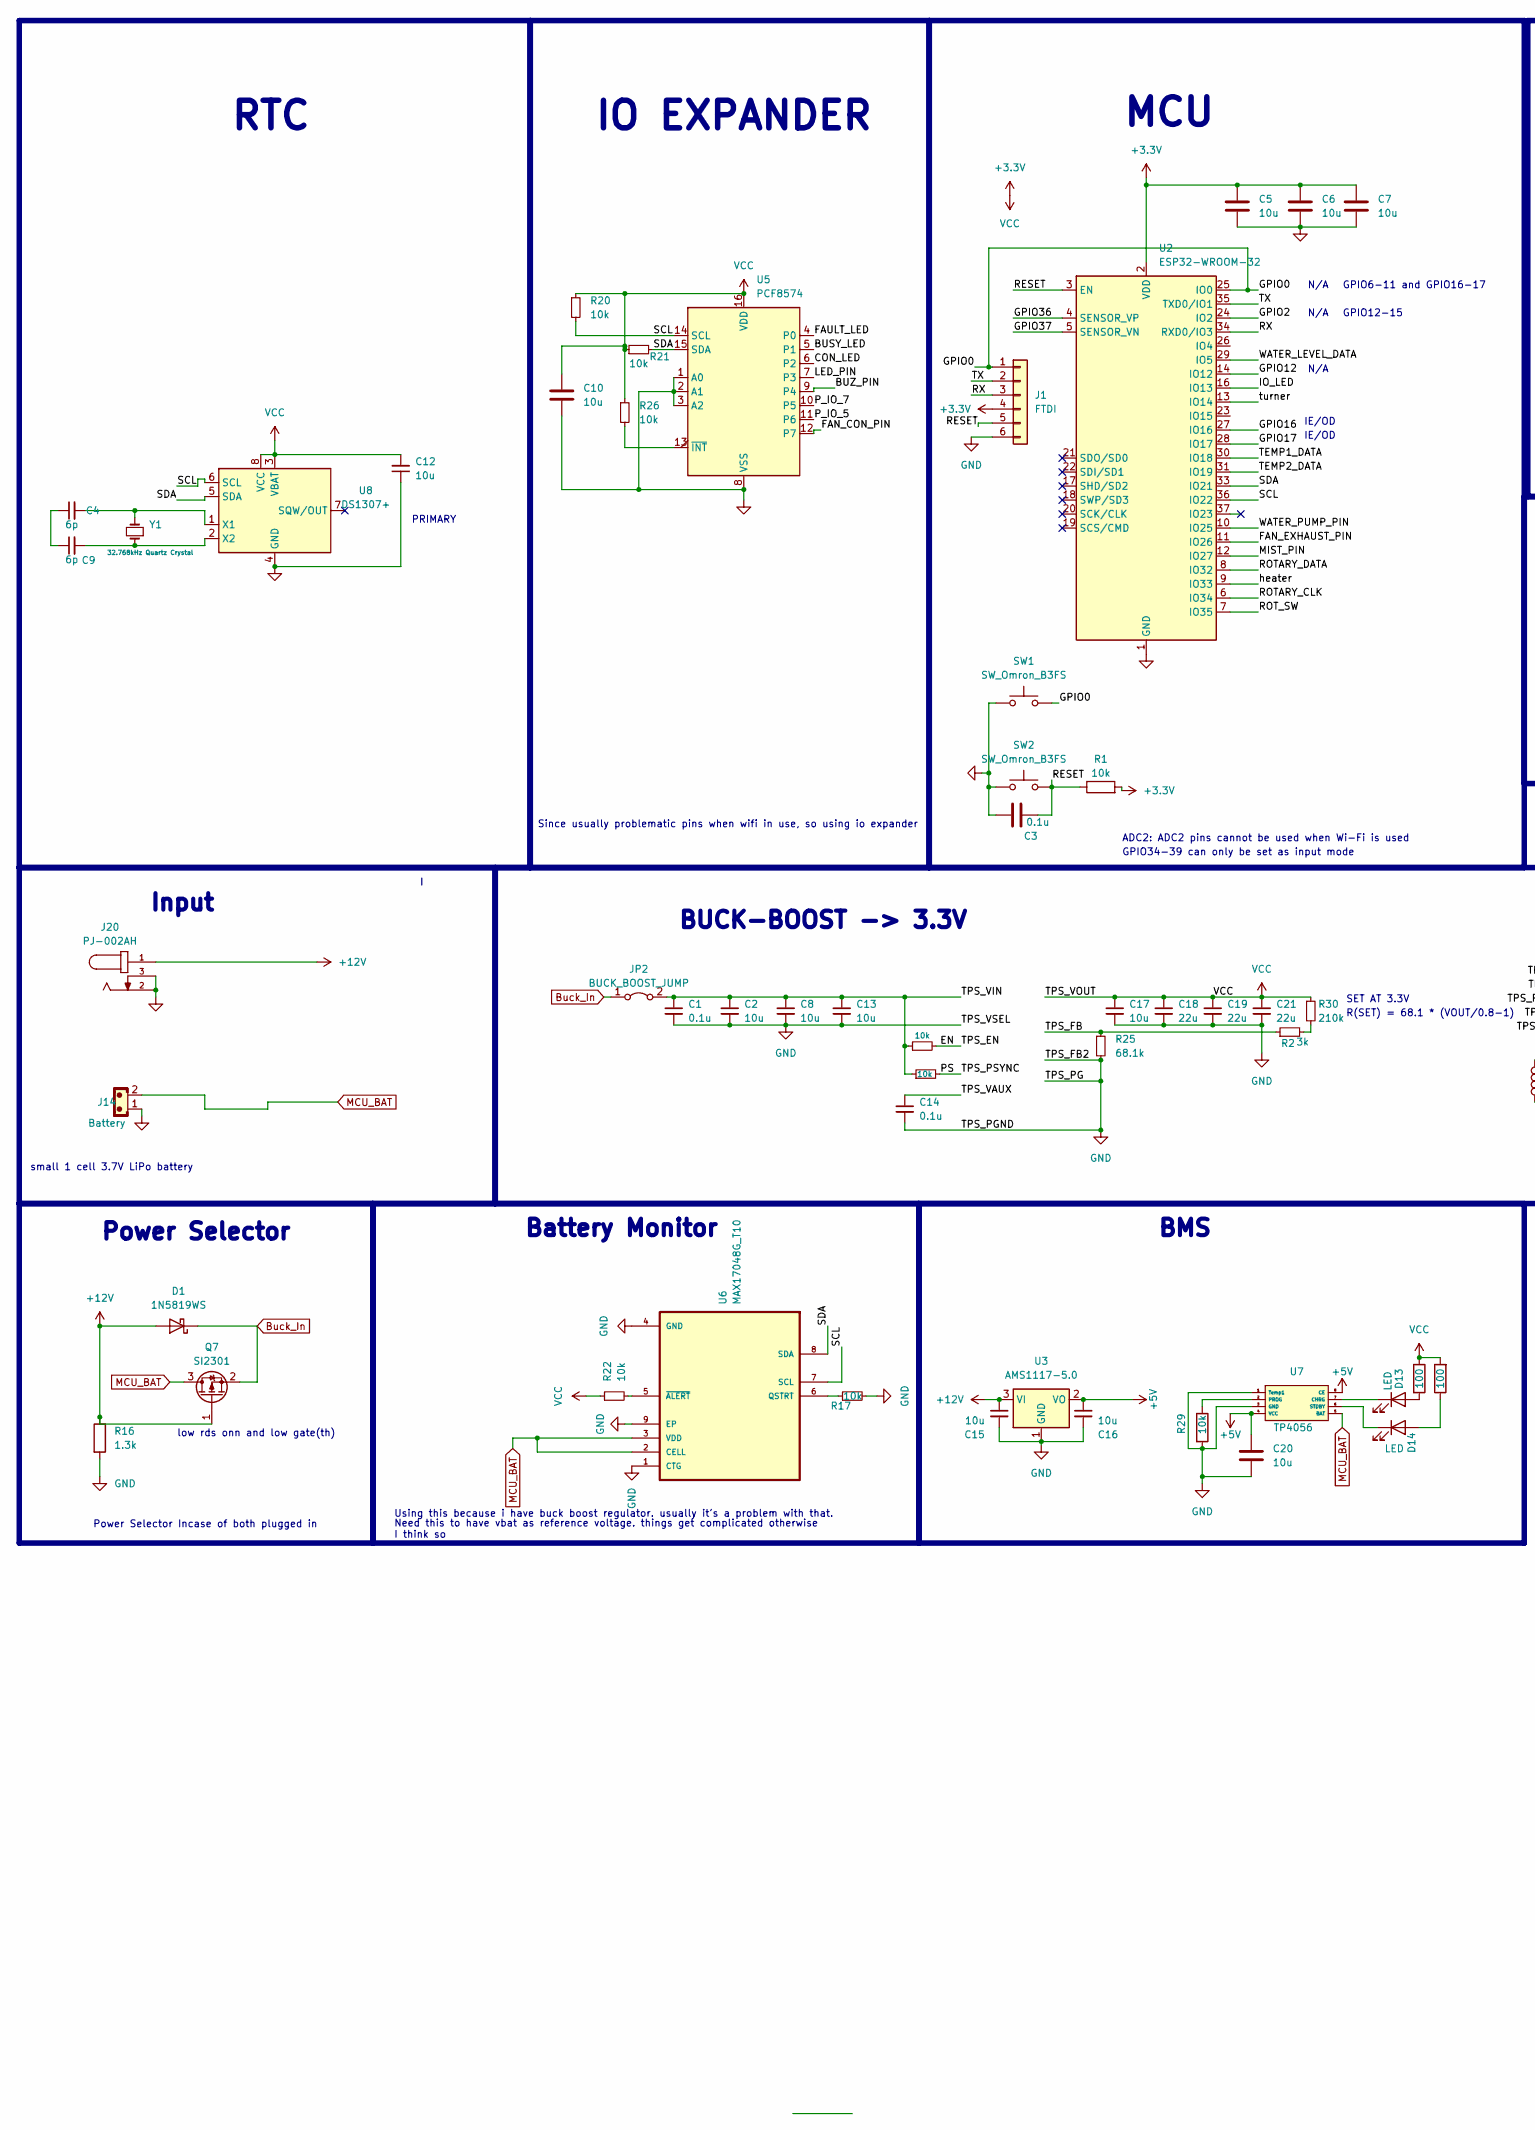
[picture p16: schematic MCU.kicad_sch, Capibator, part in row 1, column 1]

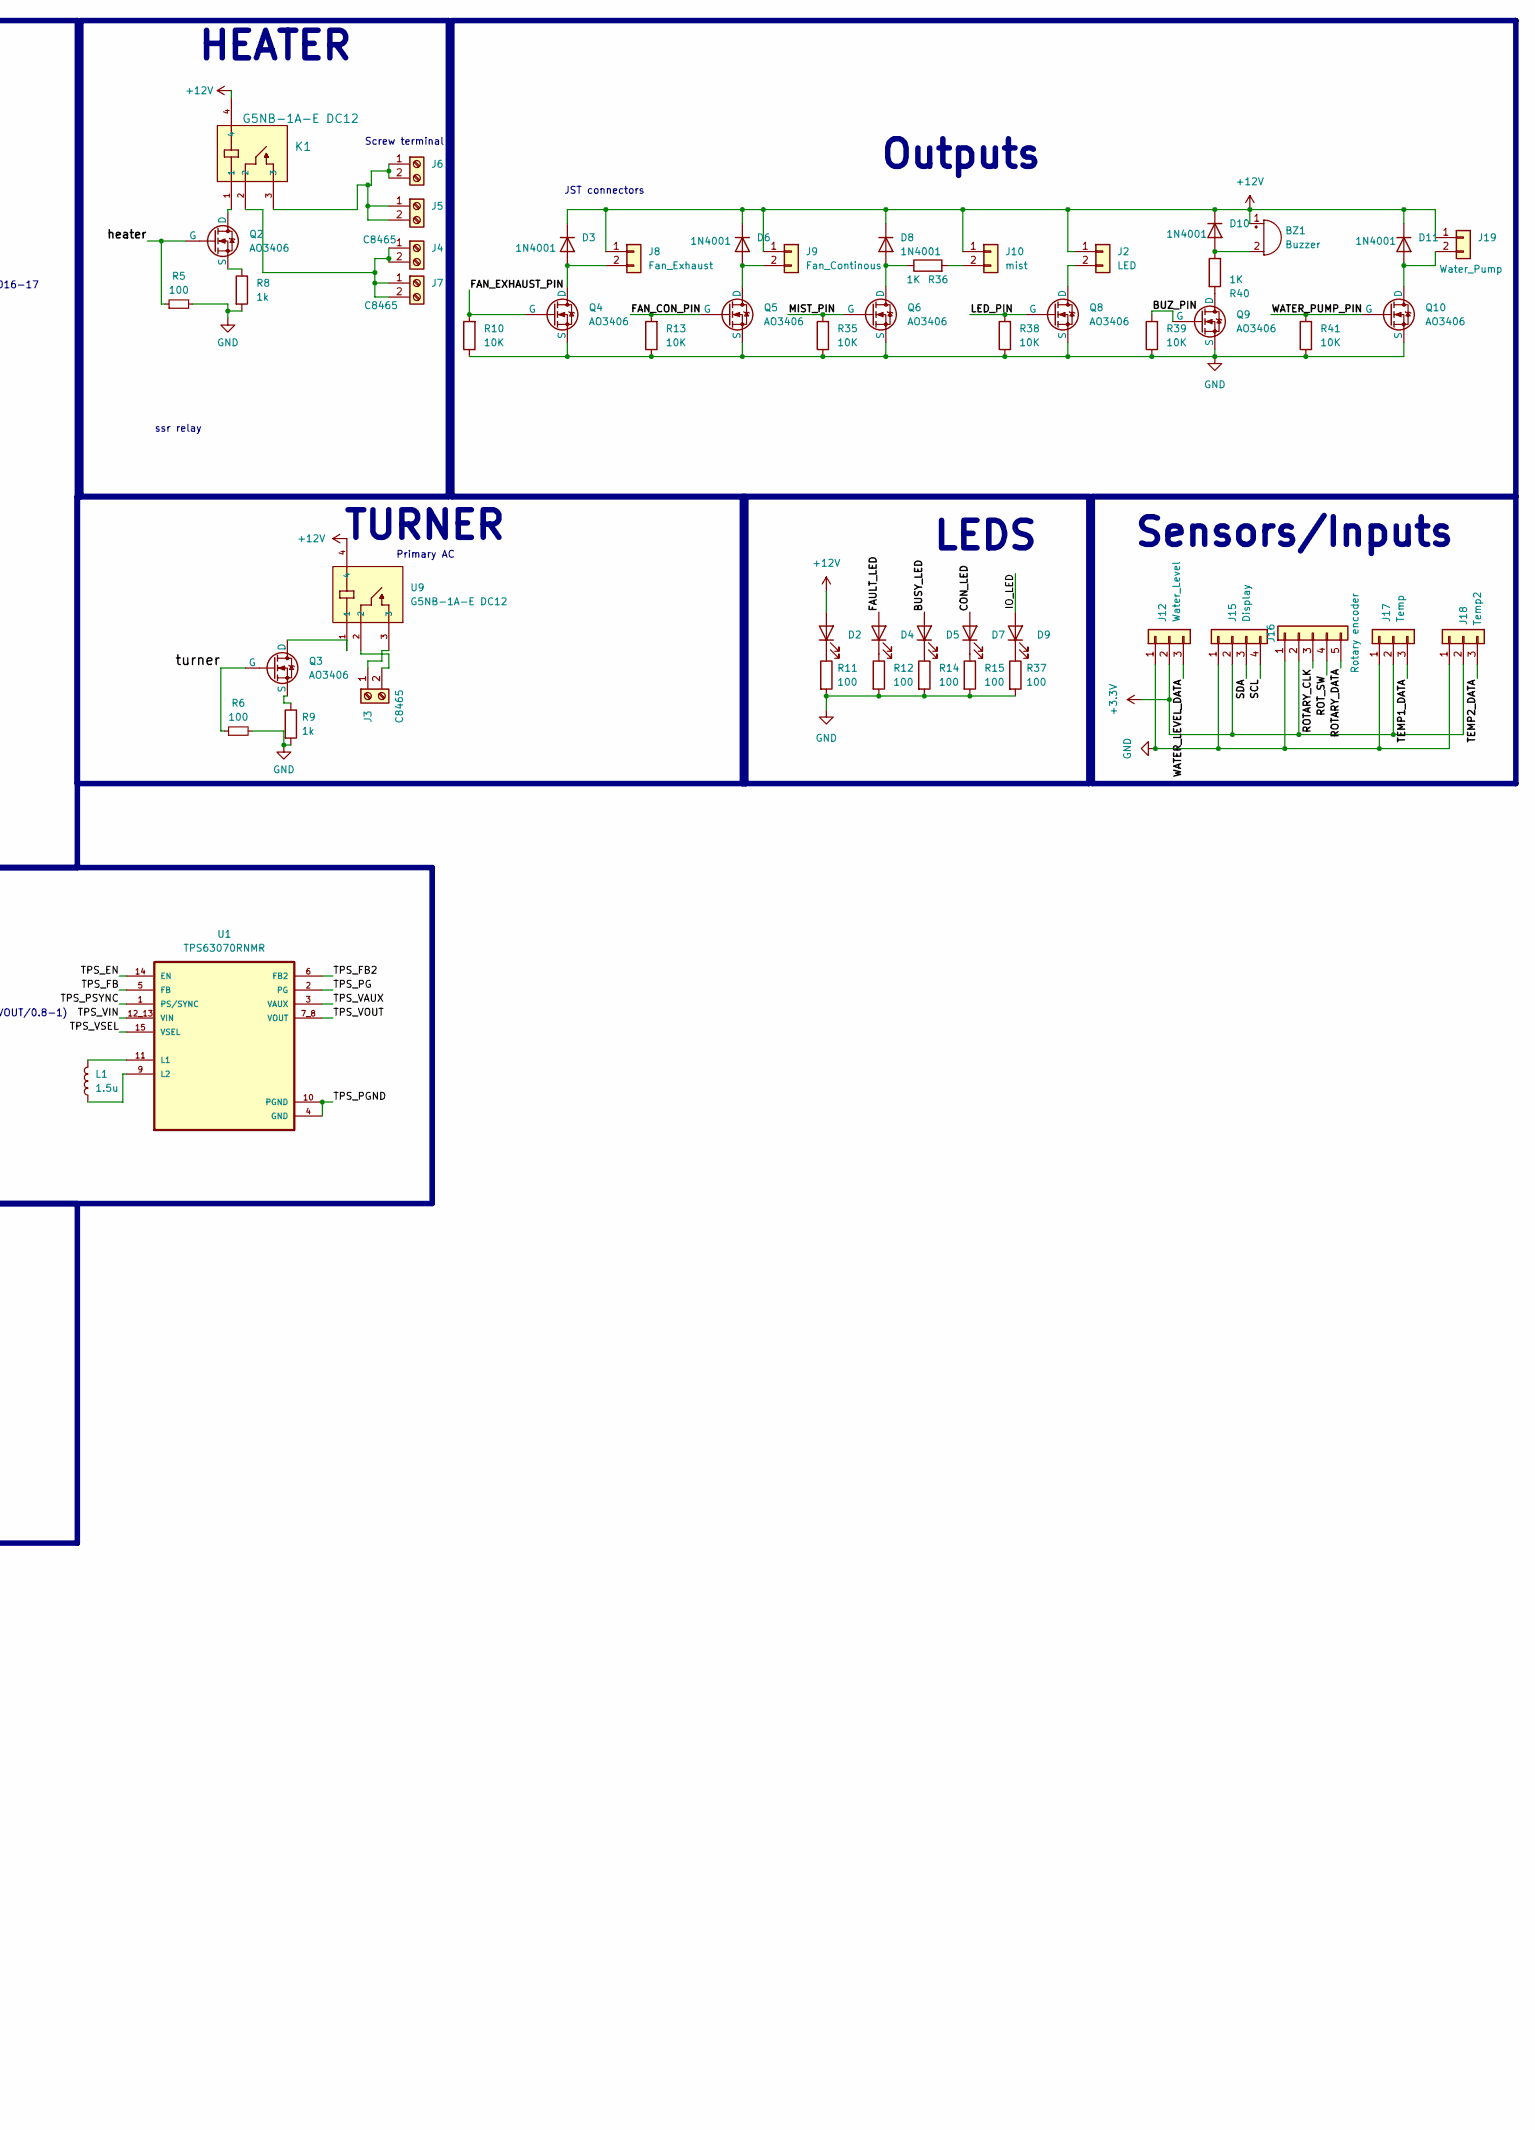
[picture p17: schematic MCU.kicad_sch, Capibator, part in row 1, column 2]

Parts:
BZ1: Buzzer; Buzzer_12x9.5RM7.6
C1, C3, C14: 0.1u; C_0805_2012Metric
C2, C5, C6, C7, C8, C10, C12, C13, C15, C16, C20: 10u; C_0805_2012Metric
C4, C9: 6p; C_0805_2012Metric
C17: 10u; R_0805_2012Metric
C18, C19, C21: 22u; R_0805_2012Metric
D1: 1N5819WS; D_SOD-323F
D2: LED_PWR; LED_0805_2012Metric
D3, D6, D8, D10, D11: 1N4001; D_SOD-123F
D4: FAULT_LED; LED_0805_2012Metric
D5: BUSY_LED; D_0805_2012Metric
D7: CONNECTIVITY_LED; LED_0805_2012Metric
D9, D13, D14: LED; LED_0805_2012Metric
J1: FTDI; PinHeader_1x06_P2.54mm_Vertical
J2: LED; JST_GH_SM02B-GHS-TB_1x02-1MP_P1.25mm_Horizontal
J3, J4, J5, J6, J7: C8465; TerminalBlock_Altech_AK300-2_P5.00mm
J8: Fan_Exhaust; JST_GH_SM02B-GHS-TB_1x02-1MP_P1.25mm_Horizontal
J9: Fan_Continous; JST_GH_SM02B-GHS-TB_1x02-1MP_P1.25mm_Horizontal
J10: mist; JST_GH_SM02B-GHS-TB_1x02-1MP_P1.25mm_Horizontal
J12: Water_Level; JST_GH_SM03B-GHS-TB_1x03-1MP_P1.25mm_Horizontal
J14: Battery; JST_EH_B2B-EH-A_1x02_P2.50mm_Vertical
J15: Display; JST_GH_BM04B-GHS-TBT_1x04-1MP_P1.25mm_Vertical
J16: Rotary encoder; JST_GH_BM05B-GHS-TBT_1x05-1MP_P1.25mm_Vertical
J17: Temp; JST_GH_SM03B-GHS-TB_1x03-1MP_P1.25mm_Horizontal
J18: Temp2; JST_GH_SM03B-GHS-TB_1x03-1MP_P1.25mm_Horizontal
J19: Water_Pump; JST_GH_SM02B-GHS-TB_1x02-1MP_P1.25mm_Horizontal
J20: PJ-002AH; CUI_PJ-002AH
JP2: BUCK_BOOST_JUMP; SolderJumper-2_P1.3mm_Bridged_RoundedPad1.0x1.5mm
K1: G5NB-1A-E DC12; RELAY_G5NB-1A_DC5_OMR; MANUFACTURER_PART_NUMBER G5NB-1A-E DC12
L1: 1.5u; L_Murata_LQH2MCNxxxx02_2.0x1.6mm
Q2, Q3, Q4, Q5, Q6, Q8, Q9, Q10: AO3406; SOT-23
Q7: SI2301; SOT-23
R1, R17, R20, R21, R22, R23, R24, R26, R29: 10k; R_0805_2012Metric
R2: 3k; R_0805_2012Metric
R5, R6, R11, R12, R14, R15, R31, R32, R37: 100; R_0805_2012Metric
R8, R9: 1k; R_0805_2012Metric
R10, R13, R35, R38, R39, R41: 10K; R_0805_2012Metric
R16: 1.3k; R_0805_2012Metric
R25: 68.1k; R_0805_2012Metric
R30: 210k; R_0805_2012Metric
R36: 1K; D_SOD-123F
R40: 1K; R_0805_2012Metric
SW1, SW2: SW_Omron_B3FS; SW_SPST_Omron_B3FS-100xP
U1: TPS63070RNMR; VREG_TPS63070RNMR
U2: ESP32-WROOM-32
U3: AMS1117-5.0; SOT-223-3_TabPin2
U5: PCF8574; SOIC127P1032X265-16N
U6: MAX17048G_T10; SON50P200X200X80-9N
U7: TP4056; SOP127P600X175-9N
U8: DS1307+; 21-0041B_8
U9: G5NB-1A-E DC12; RELAY_G5NB-1A_DC5_OMR; MANUFACTURER_PART_NUMBER G5NB-1A-E DC12
Y1: 32.768kHz Quartz Crystal; Crystal_SMD_2012-2Pin_2.0x1.2mm_HandSoldering

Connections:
12V_status: U2.23 (IO15)
+3.3V: C5.2, C6.1, C7.1, C10.2, C12.2, C17.1, C18.1, C19.1, C21.1, J1.4, J12.2, J15.2, J16.2, J17.2, J18.2, R1.2, R20.1, R21.1, R22.1, R26.1, R30.1, R31.1, R32.2, U1.7_8 (VOUT), U2.2 (VDD), U5.16 (VDD), U8.3 (VBAT), U8.8 (VCC); also elsewhere on the board
+5V: C16.1, C20.1, U3.2 (VO), U7.4 (VCC), U7.8 (CE)
+12V: BZ1.1 (-), C15.1, D1.2 (A), D2.2 (A), D3.1 (K), D6.1 (K), D8.1 (K), D10.1 (K), D11.1 (K), J2.1, J8.1, J9.1, J10.1, J19.1, J20.1, K1.4, Q7.1 (G), R16.1, U3.3 (VI), U9.4
/MCU/BUSY_LED: D5.2 (A), U5.5 (P1)
/MCU/BUZ_PIN: Q9.2 (G), R39.2, U5.9 (P4)
/MCU/CON_LED: D7.2 (A), U5.6 (P2)
/MCU/EN: R23.2, U1.14 (EN)
/MCU/FAN_CON_PIN: Q5.2 (G), R13.2, U5.12 (P7)
/MCU/FAN_EXHAUST_PIN: Q4.2 (G), R10.2, U2.11 (IO26)
/MCU/FAULT_LED: D4.2 (A), U5.4 (P0)
/MCU/GPIO0: J1.1, SW1.2, U2.25 (IO0)
/MCU/GPIO2: U2.24 (IO2)
/MCU/GPIO12: U2.14 (IO12)
/MCU/GPIO16: U2.27 (IO16)
/MCU/GPIO17: U2.28 (IO17)
/MCU/GPIO36: U2.4 (SENSOR_VP)
/MCU/GPIO37: U2.5 (SENSOR_VN)
/MCU/IO_LED: D9.2 (A), U2.16 (IO13)
/MCU/LED_PIN: Q8.2 (G), R38.2, U5.7 (P3)
/MCU/MIST_PIN: Q6.2 (G), R35.2, U2.12 (IO27)
/MCU/PS: R24.2, U1.1 (PS/SYNC)
/MCU/P_IO_5: U5.11 (P6)
/MCU/P_IO_7: U5.10 (P5)
/MCU/RESET: C3.2, J1.5, R1.1, SW2.2, U2.3 (EN)
/MCU/ROTARY_CLK: J16.3, U2.6 (IO34)
/MCU/ROTARY_DATA: J16.5, U2.8 (IO32)
/MCU/ROT_SW: J16.4, U2.7 (IO35)
/MCU/RX: J1.3, U2.34 (RXD0/IO3)
/MCU/SCL: J15.4, R20.2, U2.36 (IO22), U5.14 (SCL), U6.7 (SCL), U8.6 (SCL); also elsewhere on the board
/MCU/SDA: J15.3, R21.2, U2.33 (IO21), U5.15 (SDA), U6.8 (SDA), U8.5 (SDA)
/MCU/TEMP1_DATA: J17.3, U2.30 (IO18)
/MCU/TEMP2_DATA: J18.3, U2.31 (IO19)
/MCU/TPS_FB: R2.1, R25.1, U1.5 (FB)
/MCU/TPS_VAUX: C14.1, U1.3 (VAUX)
/MCU/TPS_VIN: C1.1, C2.1, C8.1, C13.1, JP2.2 (B), R23.1, R24.1, U1.12_13 (VIN)
/MCU/TX: J1.2, U2.35 (TXD0/IO1)
/MCU/WATER_LEVEL_DATA: J12.3, U2.29 (IO5)
/MCU/WATER_PUMP_PIN: Q10.2 (G), R41.2, U2.10 (IO25)
/MCU/heater: Q2.2 (G), R5.1, U2.9 (IO33)
/MCU/turner: Q3.2 (G), R6.1, U2.13 (IO14)
Buck_In: D1.1 (K), JP2.1 (A), Q7.2 (S)
GND: C1.2, C2.2, C3.1, C5.1, C6.2, C7.2, C8.2, C10.1, C12.1, C13.2, C14.2, C15.2, C16.2, C17.2, C18.2, C19.2, C20.2, C21.2, J1.6, J12.1, J14.1, J15.1, J16.1, J17.1, J18.1, J20.2, J20.3, Q4.3 (S), Q5.3 (S), Q6.3 (S), Q8.3 (S), Q9.3 (S), Q10.3 (S), R5.2, R6.2, R8.2, R9.2, R10.1, R11.2, R12.2, R13.1, R14.2, R15.2, R16.2, R17.2, R25.2, R29.2, R35.1, R37.2, R38.1, R39.1, R41.1, SW1.1, SW2.1, U1.2 (PG), U1.4 (GND), U1.6 (FB2), U1.10 (PGND), U1.15 (VSEL), U2.1 (GND), U2.15 (GND), U2.38 (GND), U2.39 (GND), U3.1 (GND), U5.1 (A0), U5.2 (A1), U5.3 (A2), U5.8 (VSS), U6.1 (CTG), U6.4 (GND), U6.9 (EP), U7.1 (Temp1), U7.3 (GND), U8.4 (GND)
MCU_BAT: J14.2, Q7.3 (D), U6.2 (CELL), U6.3 (VDD), U7.5 (BAT)
unnamed: BZ1.2 (+), D10.2 (A), R40.1
unnamed: C4.1, C9.1
unnamed: D2.1 (K), R11.1
unnamed: D3.2 (A), J8.2, Q4.1 (D)
unnamed: D4.1 (K), R12.1
unnamed: D5.1 (K), R14.1
unnamed: D6.2 (A), J9.2, Q5.1 (D)
unnamed: D7.1 (K), R15.1
unnamed: D8.2 (A), Q6.1 (D), R36.1
unnamed: D9.1 (K), R37.1
unnamed: D11.2 (A), J19.2, Q10.1 (D)
unnamed: D13.2 (A), R31.2
unnamed: D13.1 (K), U7.7 (CHRG)
unnamed: D14.2 (A), R32.1
unnamed: D14.1 (K), U7.6 (STDBY)
unnamed: J2.2, Q8.1 (D)
unnamed: J3.1, U9.3
unnamed: J3.2, U9.2
unnamed: J4.1, J4.2, J7.1, J7.2, K1.2
unnamed: J5.1, J5.2, J6.1, J6.2, K1.3
unnamed: J10.2, R36.2
unnamed: K1.1, Q2.1 (D)
unnamed: Q2.3 (S), R8.1
unnamed: Q3.1 (D), U9.1
unnamed: Q3.3 (S), R9.1
unnamed: Q9.1 (D), R40.2
unnamed: R2.2, R30.2
unnamed: L1.2, U1.11 (L1)
unnamed: L1.1, U1.9 (L2)
unnamed: R26.2, U5.13 (~INT)
unnamed: R17.1, U6.6 (QSTRT)
unnamed: R22.2, U6.5 (~ALERT)
unnamed: R29.1, U7.2 (PROG)
unnamed: C4.2, U8.1 (X1), Y1.2
unnamed: C9.2, U8.2 (X2), Y1.1

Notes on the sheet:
Battery Monitor
RTC
LEDS
Using this because i have buck boost regulator. usually it's a problem with that.
low rds onn and low gate(th)
MCU
GPIO34-39 can only be set as input mode
ssr relay
PRIMARY
BMS
GPIO6-11 and GPIO16-17
IE/OD
N/A
Screw terminal
R(SET) = 68.1 * (VOUT/0.8-1)
ADC2: ADC2 pins cannot be used when Wi-Fi is used
IO EXPANDER
Outputs
HEATER
SET AT 3.3V
TURNER
small 1 cell 3.7V LiPo battery
Need this to have vbat as reference voltage. things get complicated otherwise I think so
BUCK-BOOST -> 3.3V
JST connectors
Power Selector Incase of both plugged in
Sensors/Inputs
Since usually problematic pins when wifi in use, so using io expander
Primary AC
GPIO12-15
Input
Power Selector

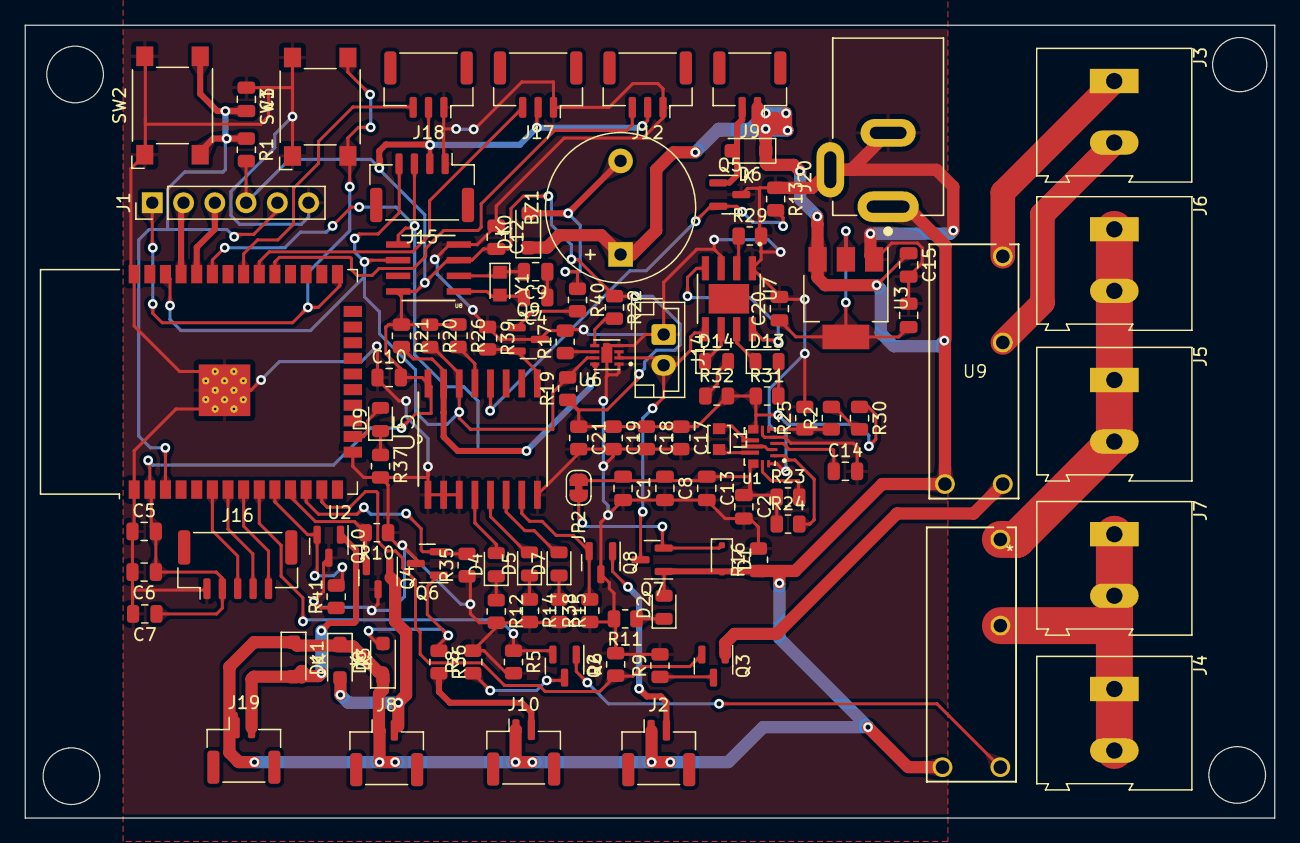
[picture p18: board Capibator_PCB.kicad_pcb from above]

Board: 2 copper layers, 101.5 x 64.4 mm, 108 parts (0 on the bottom side), 70 nets.

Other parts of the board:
R19: 10k; R_0805_2012Metric

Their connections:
+3.3V: R19.1; also elsewhere on the board
/MCU/SCL: R19.2; also elsewhere on the board

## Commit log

2024-01-21 mcu + in/out
    [Battery_Backup.kicad_sch, Capibator_PCB.csv, Capibator_PCB.kicad_pcb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]
2024-01-23 Power Section done + added backup lipo
    [Battery_Backup.kicad_sch, MCU.kicad_sch, outputs.kicad_sch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]
2024-01-23 fixed R values
    [rtc.kicad_sch, untitled.kicad_sch]
2024-01-24 added io expander + rtc + fuel guage
    [MCU.kicad_sch, power.kicad_sch, rtc.kicad_sch]
2024-02-05 Schematic Completed
    [Battery_Backup.kicad_sch, Capibator_PCB.kicad_sch, MCU.kicad_sch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]
2024-02-05 cleaned up file system
    [Battery_Backup.kicad_sch, heater.kicad_sch, rtc.kicad_sch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]
2024-03-13 assigned footprints. another look needed. moving to pcb
    [Capibator_PCB.csv, Capibator_PCB.kicad_sch, MCU.kicad_sch]
2024-03-14 started pcb and basic alignment
    [Capibator_PCB.kicad_pcb, MCU.kicad_sch]
2024-03-26 started pcb
    [Capibator_PCB.kicad_pcb, Capibator_PCB.kicad_sch, MCU.kicad_sch]
2024-06-16 improved schematic
    [MCU.kicad_sch]
2024-06-21 first revision of pcb ready. very crude.. needs another looky
    [Capibator_PCB.kicad_pcb, Capibator_PCB.kicad_sch, DS1307ZTR.step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]
2024-06-21 add models for better visuals
    [Capibator_PCB.kicad_pcb]
2024-06-22 started version 2, better placements without routing
    [3JL-25S-4244.step, Capibator_PCB.kicad_pcb]
2024-06-22 changed picture in readme
    [CUI_DEVICES_PJ-002AH.step, Capibator_PCB.kicad_pcb, MAX17048G_T10.step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]
2024-06-22 generated bom for jlcpcb
    [BOM.csv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]
2024-06-22 almost done
    [Capibator_PCB.kicad_pcb]
2024-06-22 corrected few mistakes, generated correct bom with lcsc part numbers
    [BOM_Capibator.xlsx, Capibator_PCB.kicad_pcb, MCU.kicad_sch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]
2024-06-23 cleaned up tracks, added teardrops, copper fill and improved spacing
    [Capibator_PCB.kicad_pcb, MCU.kicad_sch]

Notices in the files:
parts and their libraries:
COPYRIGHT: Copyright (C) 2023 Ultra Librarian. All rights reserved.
